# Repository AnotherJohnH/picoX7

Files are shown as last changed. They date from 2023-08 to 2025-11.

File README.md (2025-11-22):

# picoX7

picox7

A software simulation of the Yamaha DX7 with a USB and physical MIDI interface for the Raspberry Pi Pico

Slightly boring [video](https://youtu.be/ZSuNV67vHK8) of the picoX7 playing the Yamaha DX7 ROM cartridge 1A patches...

picoX7 rom1A (https://youtu.be/ZSuNV67vHK8)

## Status

Done...
   + I2S (via PIO) 16-bit stereo DAC interface at 49096 Hz
   + Use of the 2nd Arm Cortex-M, 8 voices per core
   + MIDI in support via UART and USB (including SYSEX in)
   + YM21280 OPS simulation (logarithmic)
   + YM21290 EGS simulation
   + Firmware simulation including pitch envelope, LFO, key sensitivity, level scaling, amplitude modulation
   + DX7 voice patches sounding close

To do...
   - Tune EGS simulation
   - Rate scaling
   - Portamento and glissando
   - Optimise to squeeze in more voices (?)

Limitations...
   - DAC implementation is quite different to the original. Dynamic range might be reduced?
   - Hitachi 6303 (~MC6803) CPU controller and firmware are not being emulated or fully simulated
   - 8 voices are on the left channel and 8 on the right ... stereo output needs to mixed to mono externally

Deviations/enhancements compared to a real DX7...
   + Each voice has it's own LFO
   + Each voice has it's own patch state (in theory when supported could load a different patch into each voice)
   + Support for 128 voice patches (DX7 had 32 internal and 32 cartridge)

See the [software blog](https://github.com/AnotherJohnH/picoX7/wiki/Software-Blog) and [hardware blog](https://github.com/AnotherJohnH/picoX7/wiki/Hardware-Blog)  for more detailed progress updates.

## Hardware

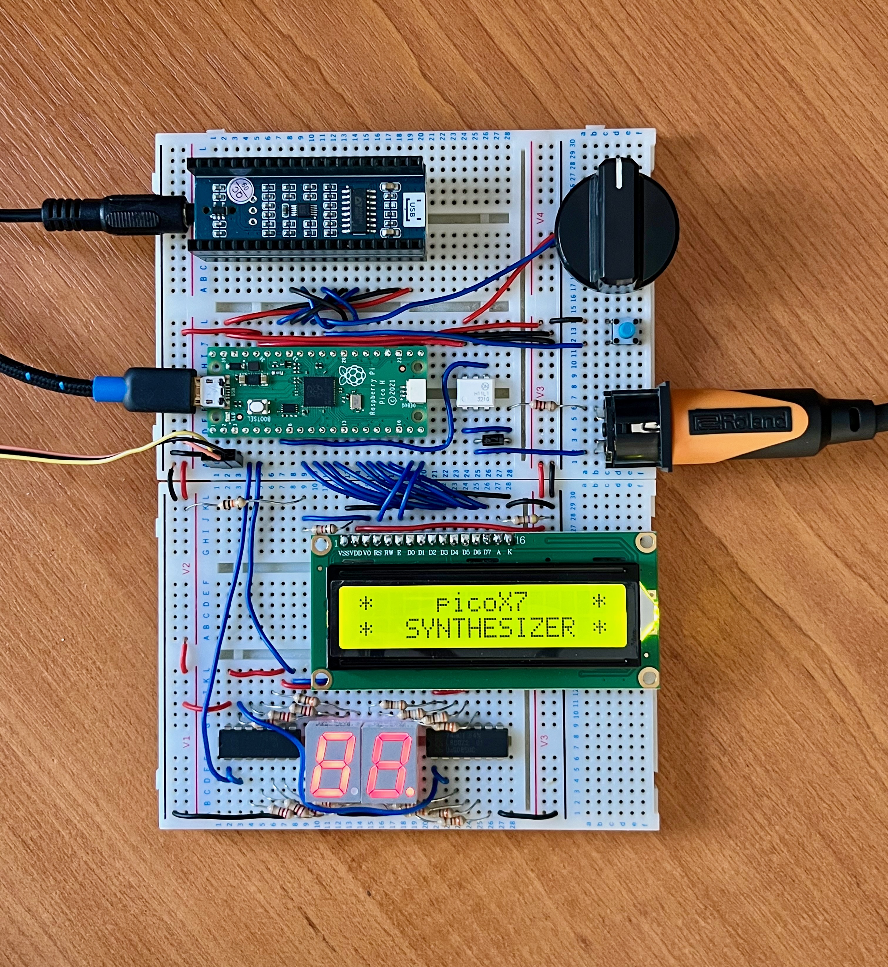
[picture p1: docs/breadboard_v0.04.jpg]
prototype


[Schematic](https://github.com/AnotherJohnH/Hardware/blob/main/picoX7/docs/schematic_v0.05.pdf) for the above.

For more information see [README](https://github.com/AnotherJohnH/Hardware/blob/main/picoX7/README.md) and the [hardware blog](https://github.com/AnotherJohnH/picoX7/wiki/Hardware-Blog)

The Pico is significantly overclocked to 191.08 MHz to support 16 voices and generate a jitter free sample rate of 49096 Hz.

RP2350 Picos as well as the older RP2040 Picos are supported.

## Software

### Checkout

This repo uses git sub-modules, so checkout using --recurse to clone all the
dependent source...

    git clone --recurse https://github.com/AnotherJohnH/picoX7.git

or

    git clone --recurse ssh://git@github.com/AnotherJohnH/picoX7.git

### Software dependencies

+ https://github.com/AnotherJohnH/Platform
+ arm-none-eabi-gcc
+ cmake via UNIX make or auto detection of ninja if installed
+ Python3
+ SDL2 (only for native test target)

### Build

Being developed on MacOS but should build on Linux too.

Indirect build of all supported targets, rpipico, rpipico2 and native with cmake and make (or ninja)...

    make

Build a single hardware target e.g. rpipico2 using cmake...

    mkdir build
    cd build
    cmake -DCMAKE_BUILD_TYPE=Release -DPLT_TARGET=rp2350 -DCMAKE_TOOLCHAIN_FILE=Platform/MTL/rp2350/target/toolchain.cmake ..
    make

flashable images will be found under the build sub-directory here...

    build/<target>/picoX7_RPIPIOC_I2S_DAC.uf2
    build/<target>/picoX7_RPIPIOC_PWM_DAC.uf2
    build/<target>/picoX7_RPIPIOC_PIMORONI_PICO_AUDIO.uf2
    build/<target>/picoX7_RPIPIOC_WAVESHARE_REV2_1.uf2
    build/<target>/picoX7_PIMORONI_VGA_DEMO.uf2

Build the native target...

    mkdir build
    cd build
    cmake -DCMAKE_BUILD_TYPE=Release -DPLT_TARGET=native ..
    make

a runable binary image will be found under the build subdirectory here...

    build/Source/picoX7_NATIVE

## License

This project is licensed under the MIT License - see the [LICENSE](LICENSE) file for details

## Acknowledgements

 + [Ken Shirriff](https://github.com/shirriff) for his very helpful series of [blogs](https://www.righto.com/2021/11/reverse-engineering-yamaha-dx7.html) reverse engineering the YM21280
 + [AJXS](https://github.com/ajxs) for their annotated [disassembly](https://ajxs.me/blog/Yamaha_DX7_Firmware_ROM_Disassembly.html) of the DX7 firmware ROM
 + The [Dexed](https://asb2m10.github.io/dexed) developers for providing an easily accessible DX7 audio reference
 + The raspberry-pi foundation for the innovative [RP2040](https://www.raspberrypi.com/documentation/microcontrollers/rp2040.html)
 + The engineers at [Yamaha](https://www.yamaha.com/en/about/design/synapses/id_009)

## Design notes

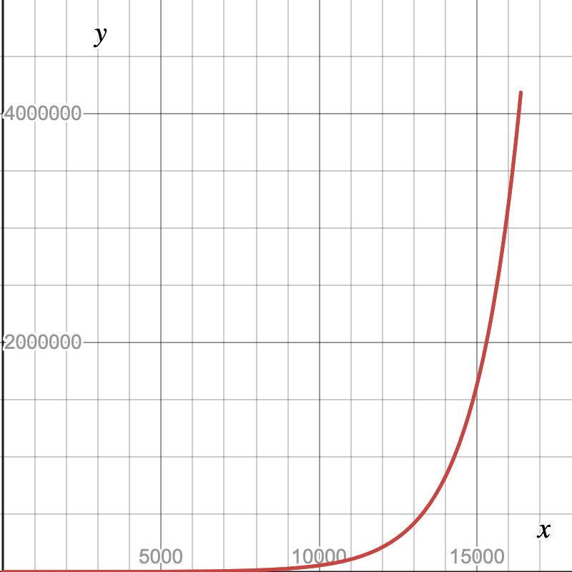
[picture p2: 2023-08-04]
docs/ym21280-exp22.png

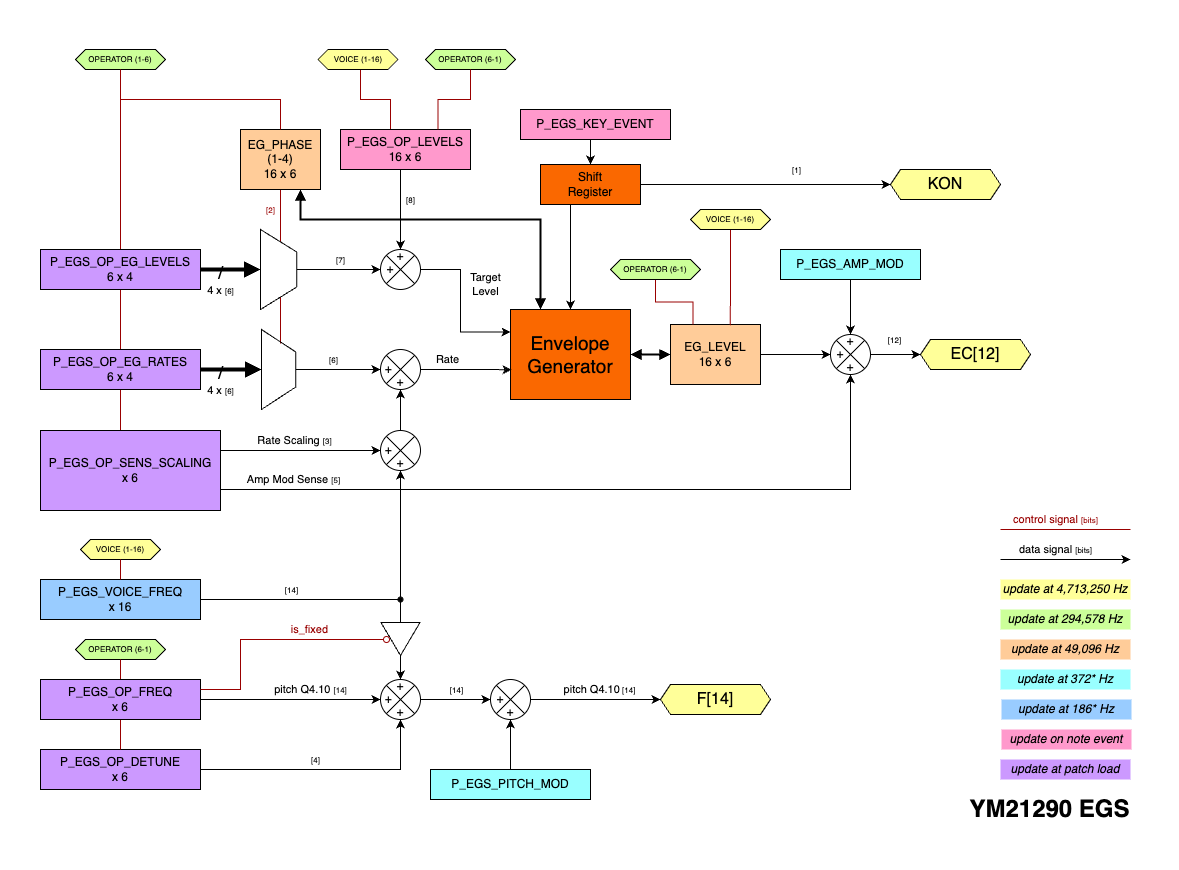
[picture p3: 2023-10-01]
docs/Research/YM21290 EGS.png

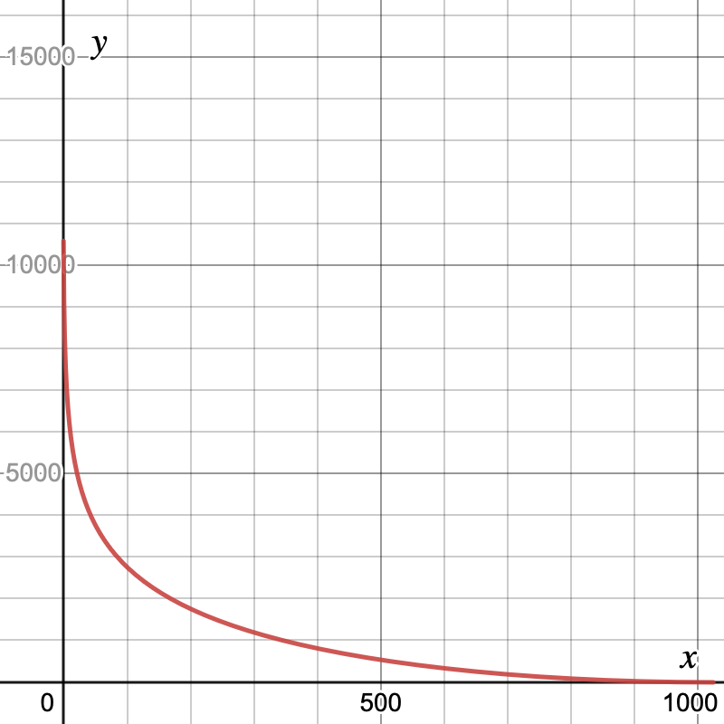
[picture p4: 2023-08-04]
docs/ym21280-log-sine.png

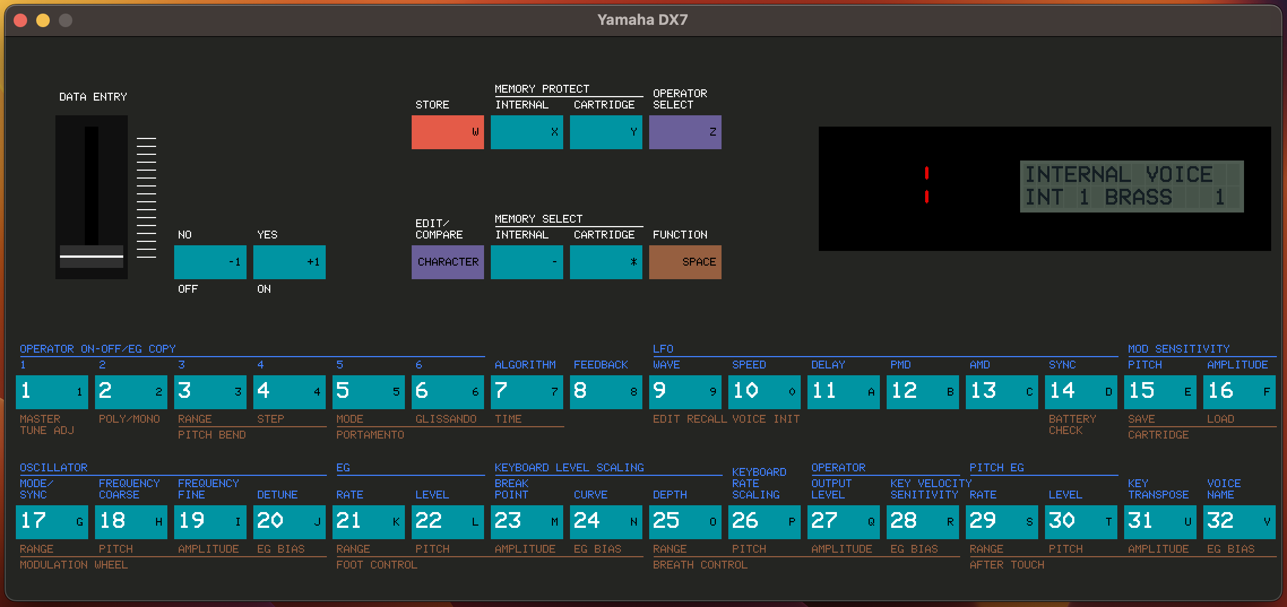
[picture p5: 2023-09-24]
docs/Research/DX7_model.png

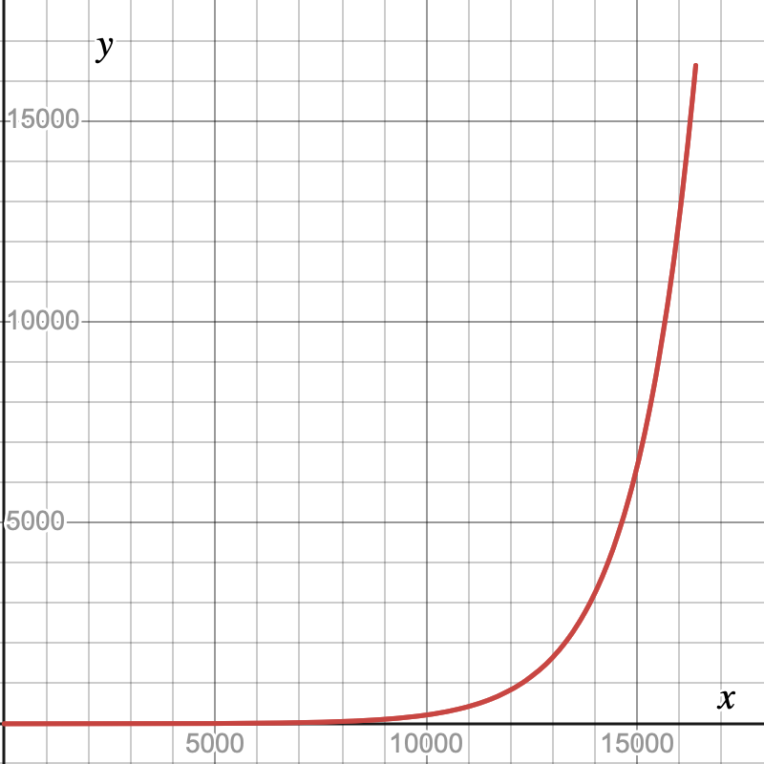
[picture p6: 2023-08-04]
docs/ym21280-exp14.png

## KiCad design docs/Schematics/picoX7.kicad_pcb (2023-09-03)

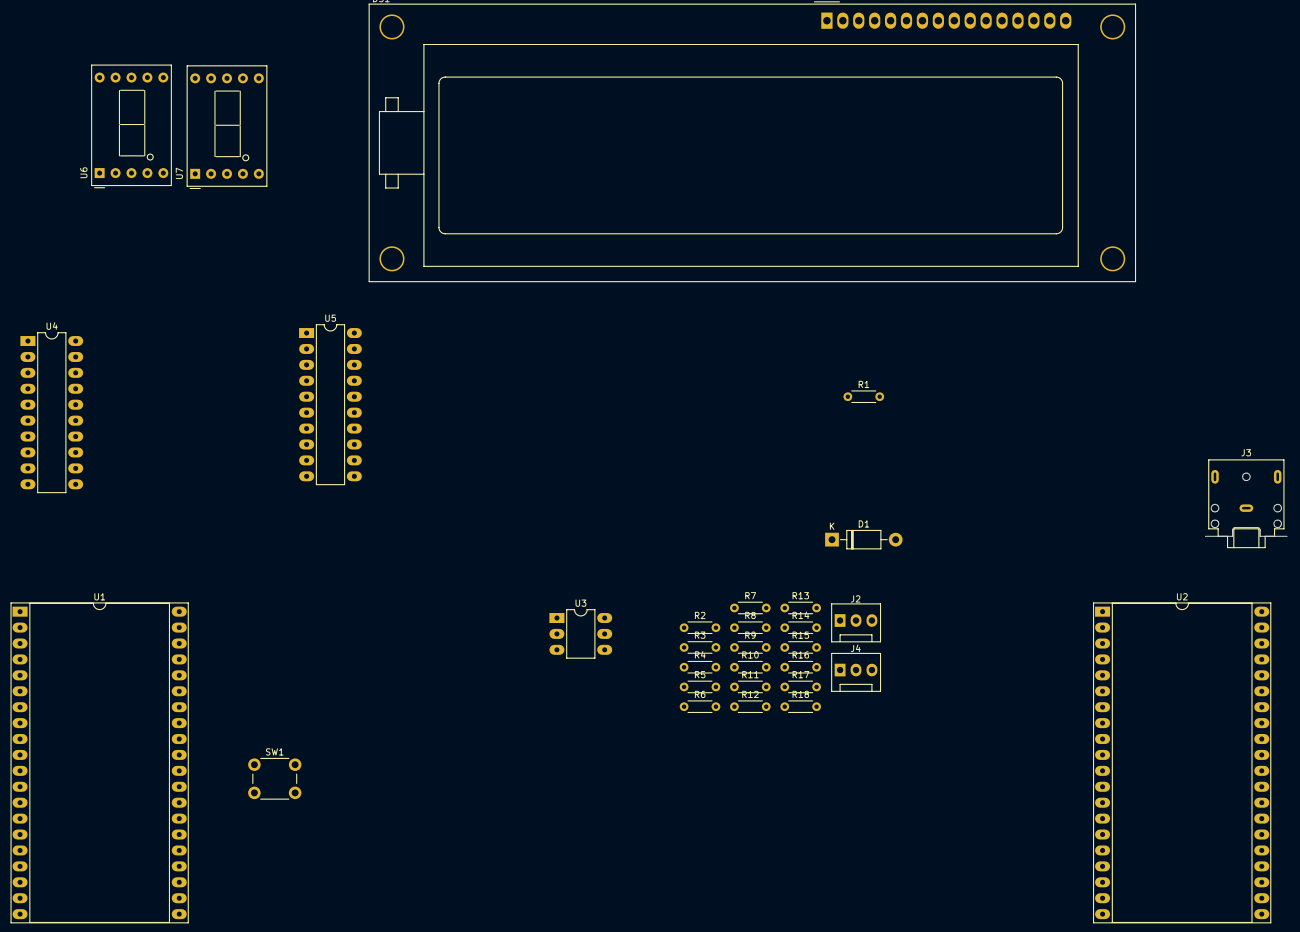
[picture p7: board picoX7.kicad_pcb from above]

Board: 2 copper layers, 31 parts (0 on the bottom side), 43 nets, no tracks yet.

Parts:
D1: 1N4001; D_DO-41_SOD81_P10.16mm_Horizontal
DS1: HY1602E
J2, J4: Debug; FanPinHeader_1x03_P2.54mm_Vertical
J3: Stereo line out; Jack_3.5mm_CUI_SJ1-3523N_Horizontal
R1: 220; R_Axial_DIN0204_L3.6mm_D1.6mm_P5.08mm_Horizontal
R2: 1K; R_Axial_DIN0204_L3.6mm_D1.6mm_P5.08mm_Horizontal
R3, R4, R5, R6, R7, R8, R9, R10, R11, R12, R13, R14, R15, R16, R17, R18: 330; R_Axial_DIN0204_L3.6mm_D1.6mm_P5.08mm_Horizontal
SW1: RST; SW_PUSH_6mm_H5mm
U1: MCU arm Cortex-M0x2; DIP-40_W25.4mm_Socket_LongPads
U2: I2S DAC; DIP-40_W25.4mm_Socket_LongPads
U3: H11L1; DIP-6_W7.62mm_LongPads
U4, U5: 74HCT374; DIP-20_W7.62mm_LongPads
U6, U7: D1X8K-14BL; D1X8K

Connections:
+3V3: U1.36 (3V3), U3.6, U4.20 (VCC), U5.20 (VCC)
+5V: DS1.2 (LEDA), DS1.4 (VDD), R2.2, U1.40 (VBUS)
/1.571072 MHz: U1.34 (GPIO28_ADC2), U2.34 (SCLK)
/12.568576 MHz: U1.31 (GPIO26_ADC0), U2.31 (MCLK)
/49.096 KHz: U1.32 (GPIO27_ADC1), U2.32 (LRCLK)
/31250 baud 8-N-1: U1.7 (GPIO5), U3.4
/D0: DS1.9 (DB0), U1.9 (GPIO6), U4.3 (D0), U5.3 (D0)
/D1: DS1.10 (DB1), U1.10 (GPIO7), U4.4 (D1), U5.4 (D1)
/D2: DS1.11 (DB2), U1.11 (GPIO8), U4.7 (D2), U5.7 (D2)
/D3: DS1.12 (DB3), U1.12 (GPIO9), U4.8 (D3), U5.8 (D3)
/D4: DS1.13 (DB4), U1.14 (GPIO10), U4.13 (D4), U5.13 (D4)
/D5: DS1.14 (DB5), U1.15 (GPIO11), U4.14 (D5), U5.14 (D5)
/D6: DS1.15 (DB6), U1.16 (GPIO12), U4.17 (D6), U5.17 (D6)
/D7: DS1.16 (DB7), U1.17 (GPIO13), U4.18 (D7), U5.18 (D7)
/I2S SD: U1.29 (GPIO22), U2.29 (DIN)
/MIDI in (RX) 115200 baud 8-N-1: J2.2, U1.2 (GPIO1)
/console (TX) 115200 baud 8-N-1: J2.1, U1.1 (GPIO0)
Earth: DS1.1 (LEDK), DS1.3 (VSS), DS1.7 (R/~W), SW1.2, U1.38 (GND), U2.3 (GND), U2.8 (GND), U2.13 (GND), U2.18 (GND), U2.23 (GND), U2.28 (GND), U2.33 (GND), U2.38 (GND), U3.5, U4.1 (OE), U4.10 (GND), U5.1 (OE), U5.10 (GND), U6.3 (CC), U6.8 (CC), U7.3 (CC), U7.8 (CC)
unnamed: D1.2 (A), U3.2
unnamed: D1.1 (K), R1.1, U3.1
unnamed: DS1.8 (E), U1.20 (GPIO15)
unnamed: DS1.6 (RS), U1.19 (GPIO14)
unnamed: J2.3, U1.3 (GND)
unnamed: U1.4 (GPIO2), U5.11 (Cp)
unnamed: U1.5 (GPIO3), U4.11 (Cp)
unnamed: SW1.1, U1.30 (RUN)
unnamed: U1.39 (VSYS), U2.39 (VSYS)
unnamed: R3.1, U6.7 (A)
unnamed: R4.1, U6.6 (B)
unnamed: R5.1, U6.4 (C)
unnamed: R6.1, U6.2 (D)
unnamed: R10.1, U6.5 (DP)
unnamed: R7.1, U6.1 (E)
unnamed: R8.1, U6.9 (F)
unnamed: R9.1, U6.10 (G)
unnamed: R11.1, U7.7 (A)
unnamed: R12.1, U7.6 (B)
unnamed: R13.1, U7.4 (C)
unnamed: R14.1, U7.2 (D)
unnamed: R18.1, U7.5 (DP)
unnamed: R15.1, U7.1 (E)
unnamed: R16.1, U7.9 (F)
unnamed: R17.1, U7.10 (G)

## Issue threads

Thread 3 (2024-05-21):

Using a well-known Pico platform to get users

magwed, 2024-05-21:
Nice project! It would be nice to have a drop-in test possibility to try out your DX7-clone at home with a MIDI-keyboard.

Maybe something like this could be a possible extra target:
https://shop.pimoroni.com/products/pimoroni-pico-vga-demo-base?variant=32369520672851

I have one at home I could test.

Still missing MIDI. Is COM-MIDI still available in the latest build? In windows it used to be resonbly easy via driver to install virtual MIDI-ports by connecting them via COM-ports. Maybe this can be used to hook it up to a DAW/MIDI-player in the nearest PC. Or if possible hooking up a USB-profile for MIDI-input that would be visible in PC. Maybe the other core could handle that?

AnotherJohnH, 2024-06-03:
That's a nice board my only complaint is that it is a bit "output heavy". Would have been nice to have a few more options or headers that could be used for input. A PS/2 keyboard socket would have made me purchase one immediately as a near perfect 80's home computer emulator platform.

However it has a header connected to UART1 that could be used as the physical MIDI in (with a suitable opto-isolater).

I expect driving the I2S on that board would require minimal changes to the existing code. (The PWM audio circuit also intrigues me, must be lower quality than the I2S DAC but would provide an exceptionally cheap alternative for a bread board build of the project.)

I've been temporarily diverted on another project but when I get back to this will see if I can quickly build an image that could receive MIDI on the UART header and drives the I2S pins on this board.

AnotherJohnH, 2024-06-05:
Have speculated support for the Pimoroni VGA Demo base board in the latest release (v0.1.6) [v0.1.6](https://github.com/AnotherJohnH/picoX7/releases/tag/v0.1.6).  To get MIDI into the board you will need to wire up a MIDI serial stream 31.25 kbaud 8-N-1 to the GPIO21 header on the base board. If you can connect and configure correctly to your host computers COM ports then you could test via [PROG_SWEEP.py](https://github.com/AnotherJohnH/picoX7/blob/main/Demo/PROG_SWEEP.py).

Be interested to here if it works.

AnotherJohnH, 2024-06-05:
A build from [aadbbf7](https://github.com/AnotherJohnH/picoX7/commit/aadbbf7b9833c38a64f3811dc1d35406773b0cee) will have some additional debug ...

1. The on-board LED will be lit if any voice is ON - useful to check if MIDI-IN is working
2. Debug console I/O should be routed out via the GPIO20 header on the Pimoroni VGA Demo build - good confidence check

NOTE: Not currently in the uf2s shared for v0.1.6

AnotherJohnH, 2024-06-11:
Currently attempting to add USB device support as a precursor to adding USB host support. If successful this should provide an easy way to control the picoX7 as a MIDI slave from a DAW. (USB host support would allow direct connection to a USB-MIDI controller)

USB is complicated and MIDI-over-USB a whole other complication on top of that, so this may take a while and I might run out of enthusiasm.

However currently have the picoX7 appearing as a low level USB device, which is a good start.

mwedmark, 2024-06-12:
OK Had a Pi Pico H available, so installed that into picoDemo board and wrote 0.16. Also found a FT232H external USB serial circuit that takes 31250 baud as a setting. So next is to mkae sure that the levels are good (3.3V) and try out some small app (yours) and see if there is any sound. It would be really cool to get Midi-yoke going and connect virtual MIDI-port directly from MIDI-out => serial port which I think should be doable. I'll keep you updated.

mwedmark, 2024-06-13:
Thanks for your work! I got sound using the above toolchain in DAC output. I wrote my own program in C# which just sets a program and then a tone! This will be fun to fiddle with going forward. Next task is to connect virtual MIDI-out to this serial port so I can mirror any MIDI-traffic out on the COM porrt and listen to MIDI-files. I'll play the piano myself to maybe I connect it and try it out going forward.

mwedmark, 2024-06-23:
Next level is fixed! It was a little bit of work to get it working in Windows.
First I tried the Hair-less MIDI-Serial driver but that only supports the standard Baud rates.
Then I installed loopMIDI to be able to create virtual MIDI-port and wrote my own .NET program to mirror bytes between MIDI-port and serial port. Works great! So now it is possible to just import a MIDI-piece into a DAW (I use LMMS now) and play notes using the picoX7. Really cool.

AnotherJohnH, 2024-06-24:
Sounds good.

With the latest patches on this project MIDI over USB is working on MacOS. I'm now able to drive the picoX7 directly with MIDI out from a DAW (Abelton live) which is very nice. I would expect MIDI over USB would work on Windows too. With this setup the only hardware required is a USB cable, a pico and a supported I2S device.

mwedmark, 2024-06-24:
Thanks! OK, that will be my next try. I like to play them directly from my MOX-8. I'm going to try and get that build pipe working so I can build my own releases.

Closed 2024-06-18.

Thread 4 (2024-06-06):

USB MIDI in

probonopd, 2024-06-06:
It would be nice to have a USB MIDI in so that we can attach USB MIDI controllers (keyboards) that do not have a DIN-style MIDI connector. For this, the Pico would need to run in USB host mode.

AnotherJohnH, 2024-06-06:
A blocker for this is I use my own SDK "Platform" that does not have USB host support.

Two solutions...

1. Port picoX7 to another raspberry Pi Pico SDK that already has USB host support. All the hardware dependencies are deliberately kept to just [picoX7.cpp](https://github.com/AnotherJohnH/picoX7/blob/main/Source/picoX7.cpp) which should help.
2. Add USB host support to the "Platform" SDK.

TBH I'm not going to do 1. but do have a USB MIDI controller that is nicer than my actual MIDI controller. I'll have a look at the rp2040 dataset to see what's involved in adding support for USB host mode.

AnotherJohnH, 2024-06-07:
... ah yes the world of USB has not simplified itself since I last visited many years ago!

But be e a good challenge and would open up some interesting possibilities for other RPi-Pico based projects.

AnotherJohnH, 2024-06-11:
Currently attempting to add USB device support as a precursor to adding USB host support. If successful this should provide an easy way to control the picoX7 as a MIDI slave from a DAW. But as you state USB host support would allow direct connection to a USB-MIDI controller.

USB is complicated and MIDI-over-USB a whole other complication on top of that, so this may take a while and I might run out of enthusiasm.

However currently have the picoX7 appearing as a low level USB device, which is a good start.

mwedmark, 2024-06-18:
Shortcut, steal with pride:
https://github.com/diyelectromusic/picodexed/tree/main/src

AnotherJohnH, 2024-06-19:
Some small progress, picoX7 now seems to work to some degree as a proper MIDI IN device. [as of patch](https://github.com/AnotherJohnH/picoX7/commit/016d613309dc3bbf84aea4c351807efaf557bc20)
Code is provisional and needs refinement. Timing seems "lumpy"

probonopd, 2024-09-09:
So you attach a MIDI controller (keyboard) using a USB OTG adapter cable to the USB jack on the RPi Pico, and power the RPi Pico via pins GND and VBUS?

AnotherJohnH, 2024-09-09:
Sorry (again) should have been clearer with my "seems to work" comment. MIDI in works but only as a USB device not as a USB host. i.e. MIDI out from my laptop over USB to the picoX7 works.

probonopd, 2024-09-09:
Thanks for the clarification. Do you plan to add USB host mode as well eventually?

AnotherJohnH, 2024-09-09:
Yep, hope to, but my current priority is to add support for the Pico-2 and the Pimoroni pico Audio.

mwedmark, 2024-09-09:
Sound great! I just bought a Pico2 and have the bigger brother picodemo so that combination would be cool to try. I guess that extra processing power will get many more tones poly. Maybe even support with 2 instances would be possible? ;-)

probonopd, 2024-10-02:
Possibly https://github.com/rppicomidi/midi2usbhost/tree/main/C-Code could be helpful? It is C code that does what we need.

probonopd, 2025-01-12:
@AnotherJohnH what do you think, could it work?

AnotherJohnH, 2025-01-19:
Possibly, however I have a personal preference of not including any significant "third party" code in my projects. The RPiPico boot ROM and a few gcc intrinsics being the current exceptions in this project. Feel free to branch and try to integrate that code yourself.

TBH I'm finding physical MIDI in and USB device MIDI in from a DAW satisfy my needs so my desire to spend the time required adding USB host support is still not a priority and would rather spend my time to improve the sound engine simulation.

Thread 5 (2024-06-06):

Display with i2s "backpack"

probonopd, 2024-06-06:
It would be nice if we could use a display module with a i2s "backpack" so that we have to wire up only 4 wires for the display instead of many.

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

AnotherJohnH, 2024-06-06:
Agree that would be nicer.

Have recently added I2C support to the SDK "Platform". Having quickly looked up an I2C 16x2 LCD can see that, unsurprsingly, the internal register set looks the same as the parallel LCD devices. So the work would be...

1.  Write a new version of [MTL/Lcd.h](https://github.com/AnotherJohnH/Platform/blob/a5334979c00c0b1448b7ad0d50a105444d258198/MTL/Lcd.h) ripping out the raw GPIO use and putting in an instance of MTL::I2C [MTL/rp2040/I2C.h](https://github.com/AnotherJohnH/Platform/blob/a5334979c00c0b1448b7ad0d50a105444d258198/MTL/chip/rp2040/I2C.h)
2. Add another hardware target to the build with some conditional compilation in [picoX7.cpp](https://github.com/AnotherJohnH/picoX7/blob/main/Source/picoX7.cpp) to select the I2C LCD driver.

Might buy one to play with when I next order some bits.

AnotherJohnH, 2024-06-07:
Have completed the trivial parts here [721a3eb](https://github.com/AnotherJohnH/picoX7/commit/721a3eb9524ba64c57f75a8670e3a4f91ae0ac6d)
Remaining work is to complete implementation of [Platform/MTL/AlphaNumLcd_I2C.h](https://github.com/AnotherJohnH/Platform/blob/master/MTL/AlphaNumLcd_I2C.h)

AnotherJohnH, 2024-09-08:
Support completed. Works for me with an AiP31068L based I2C 16x2 LCD from Waveshare via the I2C1 on pins 19 and 20. Thankyou for the suggestion that's a nice improvement. See the latest release [v0.18](https://github.com/AnotherJohnH/picoX7/releases/tag/v0.18)

AnotherJohnH, 2024-09-08:
Support completed. Works for me with an AiP31068L based I2C 16x2 LCD from Waveshare via the I2C1 on pins 19 and 20. Thankyou for the suggestion that's a nice improvement. See the latest release [v0.18](https://github.com/AnotherJohnH/picoX7/releases/tag/v0.18)

probonopd, 2024-09-28:
Which address does your display use?

AnotherJohnH, 2024-09-29:
See Platform/MTL/AlphaNumLcd_I2C.h. The address is passed as the only argument to the display driver constructor. But has a default value that matches the display I use which is 0x3E. This values is masked with 0x7F and written unshifted into the RP I2C peripherals IC_TAR (target address) register. So if you need a different address add { <addr } to the instantiation of the LCD driver in picoX7.cpp e.g.

```
static MTL::AlphaNumLcd<MTL::I2C1_P19_P20,
                        /* COLS */ 16,
                        /* ROWS */ 2> lcd { 0xHH };
```

I notice in the official SDK that similar devices use an address of 0x27 so that might be worth trying.  Maybe the device I have, a "Waveshare LCD 1602 I2C" is unusual. To be honest I struggled to find this rather important information for the display I have, on either the PiHut or Waveshare web pages. Until eventually I saw this line in a micro python example they published ...

```
#Device I2C Arress
LCD_ADDRESS  = (0x7C>>1)
```

Which, obviously, is a rather cryptic way of writing 0x3E.

AnotherJohnH, 2024-09-29:
... will post a patch making the I2C address clearer in picoX7.cpp

AnotherJohnH, 2024-09-29:
... see https://github.com/AnotherJohnH/picoX7/commit/d2f77267cb0e3e65a20598f3285e89cd395b69f4

probonopd, 2024-09-30:
Thanks @AnotherJohnH. Indeed all the generic displays I have use 0x27, so I will try that.

probonopd, 2024-09-30:
All that really happens now is that the backlight on the display (the one from the original post) gets switched off, around the time when `# 001 NAME BRASS   1  ALG 22 FBK 7 SYNC on  PMS 3 TRN 0` appears on the serial console:

```
Program  : picoX7 (WaveShare Rev2.1 I2C LCD)
Author   : Copyright (c) 2023 John D. Haughton
Version  : 0.18
Commit   : 2a2902ada41b07839b052e695fa4de73233b510b
Built    : 07:49:14 Sep 30 2024
Compiler : 9.2.1 20191025 (release) [ARM/arm-9-branch revision 277599]

# 001 NAME BRASS   1  ALG 22 FBK 7 SYNC on  PMS 3 TRN 0
LFO WAV sin SPD 37 DLY 00 PMD 05 AMD 00 SYNC off
OP AMS FREQ    DET R1 R2 R3 R4  L1 L2 L3 L4  BPT   CURVE    DEPTH RTE OUT KVS
6   0  R  1.00  0  49 99 28 68  98 98 91 00  39  -exp -exp  54 50  4   82  2
5   0  R  1.00  1  77 36 41 71  99 98 98 00  39  +lin +lin  00 00  0   98  2
4   0  R  1.00  0  77 36 41 71  99 98 98 00  39  +lin +lin  00 00  0   99  2
3   0  R  1.00 -2  77 76 82 71  99 98 98 00  39  +lin +lin  00 00  0   99  2
2   0  R  0.50  7  62 51 29 71  82 95 96 00  27  +lin -exp  00 07  0   86  0
1   0  R  0.50  7  72 76 99 71  99 88 96 00  39  +lin +lin  00 14  0   98  0
PITCH EG           84 95 95 60  50 50 50 50
```

AnotherJohnH, 2024-09-30:
Ugg :-( I guess that means the I2C address is working but the I2C interface in the Waveshare device I have is not the same as the "generic displays" that usually live at 0x27. Will dig into this a bit further when I get a chance. Do you know the part number of the I2C device on your display?

probonopd, 2024-10-01:
I think they are all using various [8574](https://www.ti.com/lit/ds/symlink/pcf8574.pdf) compatible chips. Mine says "8574T".

AnotherJohnH, 2024-10-01:
So seems there are (at least) two types of I2C 16x2 LCD....

1. The one you have uses a generic I2C bridge chip (the PCF8574) to drive the parallel interface to the old style HD44780 LCD display driver. I guess back-pack was the clue I missed. [I2C 16x2 Arduino LCD display module](https://thepihut.com/products/i2c-16x2-arduino-lcd-display-module)
2. The device I have, which uses an all in one I2C LCD driver chip.  [LCD 1602 I2C module](https://thepihut.com/products/lcd1602-i2c-module)

probonopd, 2024-10-02:
Could it be that you forgot to push Platform d6af84a04098e0b8219930b8238eb8fdf3f17c61? I am currently getting

```
Fetching submodules
  /usr/bin/git submodule sync
  /usr/bin/git -c protocol.version=2 submodule update --init --force
  Submodule 'Platform' (https://github.com/AnotherJohnH/Platform.git) registered for path 'Platform'
  Cloning into '/home/runner/work/picoX7/picoX7/Platform'...
  Error: fatal: remote error: upload-pack: not our ref d6af84a04098e0b8219930b8238eb8fdf3f17c61
  Error: fatal: Fetched in submodule path 'Platform', but it did not contain d6af84a04098e0b8219930b8238eb8fdf3f17c61. Direct fetching of that commit failed.
  Error: The process '/usr/bin/git' failed with exit code 128
```

This kind of error could be caught easily if continuous integration would be merged:

* https://github.com/AnotherJohnH/picoX7/pull/9

AnotherJohnH, 2024-10-02:
Oh, sorry about that have pushed the missing Platform patch.

probonopd, 2024-10-02:
Moving in the right direction, but not quite yet there.

When I power cycle the display, I immediately see a blinking square over a _ character. Then the screen shows the string "NTERND" followed by blanks, and the blinking square over a _ character is in the 4th from the right on the second line.

I would not be entirely surprised if some "waits" were missing, or something small along those lines.

AnotherJohnH, 2024-10-04:
After a reset the display should be....
```
*    picoX7    *
*  SYNTHESIZER *
```
and then after 2.5 seconds...
```
INTERNAL VOICE
INT 1 BRASS   1
```
so yep, seems close. I'll double check the code and the timings in particular.

AnotherJohnH, 2024-10-04:
Guessing it's got through the initialisation ok-ish.  So the general byte send code is possibly the broken part.

I'd copied the delays that I'd used in the parallel version of the driver which are (setup) 10us and (hold) 38us. The Python you linked had no delays in this area, but then Python is going to be so slow that it probably covers the requirement without trying. Looking at the C in the official pico-example can see some massive 600us delays and also the code takes time to setup the data nibble before asserting the E pin, again with a 600us delay.

The data sheet does not support the need to setup the data before asserting E, it is clear that the data is captured on the falling edge of E, which makes me suspicious of the 600us too. TBH to follow the data sheet all these drivers (mine included) should be sampling the busy flag pin instead of delays. Which I guess us coders are too lazy to do!

Have posted a [patch](https://github.com/AnotherJohnH/picoX7/commit/39e6b5d68a0a7fa364d3d5b94330636c6465c3b7) which updates the timings to 600us. If I was able to test would have tuned this down until it was just working and then doubled it.

probonopd, 2024-10-06:
Sorry to be a pain, but now I get strange special characters on the screen. I do see that the display content changes after 2.5 seconds (so it's alive), but unfortunately nothing is readable. The characters being shown seem to be entirely reproducible across reboots.

If you can give me instructions on what to change/test, I can do it.

Closed 2024-09-08.

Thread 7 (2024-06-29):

DX7 SYSEX download over USB MIDI broken

AnotherJohnH, 2024-06-29:
Be nice to be able to download SYSEX patches over USB MIDI say from Dexed. This is not working at the moment and the assumption is that these long SYSEX messages are sent using the "High Bandwidth" Data Transfer Mechanism.
Currently have only implemented the basic MIDI stream.

AnotherJohnH, 2024-06-29:
LOL seems from the USB MIDI spec. that "bulk transfer" is  the basic MIDI messages, and "Transfer bulk" is what this enhancement is about!

AnotherJohnH, 2024-06-30:
Turns out it was partly my misuse of Dexed. To send SYSEX to the picoX7 you need to also select the picoX7 as the DX7 out in the PARM popup window. With this change a SYSEX starts to be received by the picoX7 using the normal "bulk transfer" so a "Transfer bulk" end-point is not needed.

However the picoX7 crashes cacaphonically halfway through the SYSEX download.

AnotherJohnH, 2024-06-30:
Cacaphonic crash was down to too much debug printf in the USB IRQ handler. So have downloaded a dexed patch. But still testing...

AnotherJohnH, 2025-01-19:
There was also a silly bug in the generic MIDI SySex handling code in Platform. Seems fixed now as of [https://github.com/AnotherJohnH/picoX7/commit/cc8704fef1c9a08d68a0d6125e64171c9ef9e741](patch)

Closed 2025-01-19.

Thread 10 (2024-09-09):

How to use the native target on Linux?

probonopd, 2024-09-09:
How to get MIDI input into the native target on Linux and/or sound out of it?

```
./picoX7_NATIVE

Program  : picoX7 (native)
Author   : Copyright (c) 2023 John D. Haughton
Version  : 0.18
Commit   : 6381560b020c1a3617568663ccafd5c57f9183a7
Built    : 18:41:18 Sep  9 2024
Compiler : 9.4.0

# 001 NAME BRASS   1  ALG 22 FBK 7 SYNC on  PMS 3 TRN 0
LFO WAV sin SPD 37 DLY 00 PMD 05 AMD 00 SYNC off
OP AMS FREQ    DET R1 R2 R3 R4  L1 L2 L3 L4  BPT   CURVE    DEPTH RTE OUT KVS
6   0  R  1.00  0  49 99 28 68  98 98 91 00  39  -exp -exp  54 50  4   82  2
5   0  R  1.00  1  77 36 41 71  99 98 98 00  39  +lin +lin  00 00  0   98  2
4   0  R  1.00  0  77 36 41 71  99 98 98 00  39  +lin +lin  00 00  0   99  2
3   0  R  1.00 -2  77 76 82 71  99 98 98 00  39  +lin +lin  00 00  0   99  2
2   0  R  0.50  7  62 51 29 71  82 95 96 00  27  +lin -exp  00 07  0   86  0
1   0  R  0.50  7  72 76 99 71  99 88 96 00  39  +lin +lin  00 14  0   98  0
PITCH EG           84 95 95 60  50 50 50 50
```

When I play notes on an attached MIDI controller (keyboard), I hear no sound and the output on the screen does not change.
When I do `sudo cat /dev/midi3` and press some keys on the keyboard, I do see activity there.

How to analyze/debug this?

AnotherJohnH, 2024-09-09:
Ouch, sorry, I should use Linux more often! If you look in `Platform/PLT/Linux/CMakeLists.txt` you will find that the MIDI modules are stubs. e.g. compare with the `macOS` sub-directory which has actual implementations.

I have a Linux VM. Be happy to have a quick look.

AnotherJohnH, 2024-09-09:
This [patch](https://github.com/AnotherJohnH/picoX7/commit/58a0eb7a6a6f1b0d9cf4a139e7179419651d6804) should help get something working. There seems to be some significant latency. Maybe it's because I used a Linux VM or maybe it's my misuse of the Linux API?

Closed 2024-09-15.

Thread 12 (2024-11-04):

Electrical note to connect UART MIDI keyboard

sysop8866, 2024-11-04:
Hello!
I suggest you insert a 470ohm pullup resistor between pin(7)-GPIO5 Rx MIDI and 3.3V.
Without this resistor I cannot decode any data from the MIDI keyboard.
Now with this modification it works perfectly.
I compiled your software for both the RP2040 and RP2350 boards with an external DAC PCM5102 and it works well.
I congratulate you for the excellent work you have done.
Thanks
Daniele
P.S.
Sorry for my bad English!

AnotherJohnH, 2025-01-12:
(sorry for the delay in response had other priorities)
Thank you for the feedback, particularly the missing pull up, good spot!
Have posted a software fix here https://github.com/AnotherJohnH/picoX7/commit/e0d8dabb997fa5f0a68e6075255a5b83199fc15f that restores the internal pull up in software. Must have got lost at some point.

AnotherJohnH, 2025-01-12:
Should be fixed now

Closed 2025-01-12.

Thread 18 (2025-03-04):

Final output level

AnotherJohnH, 2025-03-04:
The final output level for different algorithms seems too variable. The more carriers in the final mix the lower the level. This is obviously due to the compensation factor but maybe is resolved in the real thing by the SF[3:0] signal from the OPS to the funky DAC circuit.

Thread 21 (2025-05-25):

I2C (LCD display) and UART  RX (physical MIDI) broken on RP2350

AnotherJohnH, 2025-05-25:
oops not properly tested

AnotherJohnH, 2025-05-25:
Fixed by [patch](https://github.com/AnotherJohnH/picoX7/commit/ccd13932d50590748810dbff510bee8081c6cbcd)

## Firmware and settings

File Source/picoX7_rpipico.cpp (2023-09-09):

//------------------------------------------------------------------------------
// Copyright (c) 2023 John D. Haughton
//
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
// \brief DX7 simulation for Raspberry Pi Pico

#include <cstdio>
#include <unistd.h>

#include "STB/MIDIInterface.h"

#include "MTL/MTL.h"
#include "MTL/Digital.h"
#include "MTL/Pins.h"
#include "MTL/PioAudio.h"
#include "MTL/Led7Seg.h"
#include "MTL/Lcd.h"
#include "MTL/rp2040/Uart.h"
#include "MTL/rp2040/Clocks.h"
#include "MTL/rp2040/Adc.h"

#include "Usage.h"
#include "DX7/Synth.h"

static const unsigned SAMPLE_RATE = 49096;                   // DAC sample rate (Hz)
static const unsigned TICK_RATE   = 375;                     // 6800 firmware tick (375 Hz)
static const unsigned BUFFER_SIZE = SAMPLE_RATE / TICK_RATE; // DAC buffer size (samples)
static const unsigned NUM_VOICES  = 6;                       // Polyphony

//! Select a system clock with clean division to 49.1 KHz
//namespace MTL { Clocks::SysFreq clocks_sys_freq = Clocks::SYS_FREQ_137_48_MHZ; }

//! Select a system clock with clean division to 49.095 KHz
//namespace MTL { Clocks::SysFreq clocks_sys_freq = Clocks::SYS_FREQ_157_10_MHZ; }

//! Select a system clock with clean division to 49.096 KHz
namespace MTL { Clocks::SysFreq clocks_sys_freq = Clocks::SYS_FREQ_191_08_MHZ; }


// --- RP2040 module LED --------------------------------------------------------------

MTL::Digital::Out<MTL::PIN_LED1> led;


// --- MIDI-in -----------------------------------------------------------------

//! MIDI in at 31250 baud
class MidiIn1 : public MIDI::Interface
{
public:
   MidiIn1(MIDI::Instrument& instrument)
      : MIDI::Interface(instrument)
   {}

   bool empty() const override { return uart.empty(); }

   uint8_t rx() override { return uart.rx(); }

private:
   MTL::Uart1 uart{31250, 8, MTL::UART::NONE, 1};
};


// --- debug MIDI-in -----------------------------------------------------------

//! Slow MIDI in via the console UART
class MidiIn0 : public MIDI::Interface
{
public:
   MidiIn0(MIDI::Instrument& instrument)
      : MIDI::Interface(instrument)
   {}

   bool empty() const override { return MTL_getch_empty(); }

   uint8_t rx() override { return MTL_getch(); }
};


// --- 7-segment LED display ---------------------------------------------------

static MTL::Led7Seg</* PIN_CLK */  MTL::PIN_5,
                    /* PIN_DATA */ MTL::PIN_4,
                    /* NUM_DIGITS */ 2> led_7seg;

void SynthIO::displayLED(unsigned number)
{
   led_7seg.printDec(number, number >= 100 ? 0 : 3);
}


// --- 16x12 LCD display -------------------------------------------------------

static MTL::Lcd</* PIN_DATA */   MTL::PIN_9,
                /* PIN_R_S */    MTL::PIN_19,
                /* PIN_ENABLE */ MTL::PIN_20,
                /* COLS */       16,
                /* ROWS */       2,
                /* DL_8BIT */    true> lcd;

void SynthIO::displayLCD(unsigned row, const char* text)
{
   lcd.move(0, row);
   lcd.print(text);
}


// --- ADC ---------------------------------------------------------------------

MTL::Adc adc;

unsigned SynthIO::readSliderADC()
{
   static bool first_pass{true};

   if (first_pass)
   {
      adc.startCont(/* channel */ 0);
   }

   return adc.scaledResult(100);
}


// -----------------------------------------------------------------------------

static Usage                            usage {};
static Synth<NUM_VOICES, /* AMP_N */ 8> synth {};

// --- DAC ---------------------------------------------------------------------

//! 49.1 KHz I2S DAC, with pinout for Waveshare Pico-Audio
//  buffer sized to give a 375 Hz tick
static MTL::PioAudio<MTL::Pio0,BUFFER_SIZE> audio {SAMPLE_RATE,
                                                   MTL::PIN_27,  // MCLK
                                                   MTL::PIN_29,  // SD
                                                   MTL::PIN_32}; // LRCLK + SCLK
PIO_AUDIO_ATTACH_IRQ_0(audio);

//! DAC pump call-back
void MTL::PioAudio_getSamples(uint32_t* buffer, unsigned n)
{
   usage.start();

   synth.tick();

   for(unsigned i = 0; i < n; ++i)
   {
      int16_t sample = synth();

      // Same 16-nit sample to left and right audio streams
      buffer[i] = (sample << 16) | (sample & 0xFFFF);
   }

   usage.end();
}


// --- Entry point -------------------------------------------------------------

int MTL_main()
{
   // Starting
   led = true;

   // Clear screen and cursor to home
   printf("\e[2J");
   printf("\e[1,1H");

   printf("\n");
   printf("Program  : picoX7\n");
   printf("Author   : Copyright (c) 2023 John D. Haughton\n");
   printf("Version  : %s\n", MTL_VERSION);
   printf("Commit   : %s\n", MTL_COMMIT);
   printf("Built    : %s %s\n", __TIME__, __DATE__);
   printf("Compiler : %s\n", __VERSION__);
   printf("\n");

   MidiIn0 midi_in0 {synth};
   MidiIn1 midi_in1 {synth};

   synth.programChange(0, 0);

   audio.start();

   while(true)
   {
      midi_in0.tick();
      midi_in1.tick();

#if 0
      puts("\033[H");
      printf("FLASH: %2u%%   ", usage.getFLASHUsage());
      printf("RAM: %2u%%   ", usage.getRAMUsage());
      printf("CPU: %2u%%\n", usage.getCPUUsage());

      usleep(500000);
#endif
   }

   return 0;
}

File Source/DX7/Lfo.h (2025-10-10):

//-------------------------------------------------------------------------------
// Copyright (c) 2023 John D. Haughton
// SPDX-License-Identifier: MIT
//-------------------------------------------------------------------------------

// \brief DX7 firmware simulation - LFO
//
// Credit to AJXS for his excellent disassembly of the DX7 firmware ROM

#pragma once

#include "SysEx.h"

//! DX7 LFO simulation
class Lfo
{
public:
   Lfo() = default;

   //! Get amplitude modulatiion factor (0..FF)
   uint8_t getAmpMod() const { return amp_mod; }

   //! Get pitch modulatiion factor (0..FF)
   uint8_t getPitchMod() const { return pitch_mod; }

   //! Get current amplitude output value (2's comp 8-bit)
   int8_t getAmpOutput() const { return output; }

   //! Get current pitch output value (2's comp 8-bit)
   int8_t getPitchOutput() const { return (output * pitch_mod_sense) >> 8; }

   //! Configure from SysEx program
   void load(const SysEx::Voice& patch)
   {
      // Compute LFO phase increment from LFO speed
      // Scale 0..99 to full scale 8-bit e.g. 0..255
      uint8_t  speed = (patch.lfo.speed * 660) >> 8;
      unsigned scale = 11;

      if (speed == 0)
      {
         speed = 1;                     // LFO speed 0 => 11
      }
      else if (speed >= 160)
      {
         scale += (speed - 160) >> 2;   //      LFO speed 63..99 => 1782..8670
      }                                 // else LFO speed  1..62 =>   11..1749

      phase_inc = scale * speed;


      // Compute LFO delay increment from LFO delay
      // Invert 0..99 => 99..0
      // and treat as an 7-bit floating point value _EEEMMMM
      uint8_t  delay   = 99 - patch.lfo.delay;
      uint8_t  exp     = 7 - (delay >> 4);
      uint16_t mantisa = (0b10000 | (delay & 0b1111)) << 9;
      delay_inc        = mantisa >> exp;


      // Scale 0..99 to full scale 8-bit e.g. 0..255
      pitch_mod_depth = (patch.lfo.pitch_mod_depth * 660) >> 8;

      // Scale 0..99 to full scale 8-bit e.g. 0..255
      amp_mod_depth = (patch.lfo.amp_mod_depth * 660) >> 8;

      waveform = patch.lfo.waveform;

      // Scale 0..7 to full scale 8-bit e.g. 0..255
      const uint8_t pitch_mod_sense_table[8] = {0, 10, 20, 33, 55, 92, 153, 255};
      pitch_mod_sense = pitch_mod_sense_table[patch.pitch_mod_sense];

      sync = patch.lfo.sync;
   }

   //! Start of note
   void keyOn()
   {
      delay_accum = 0;
      fade_in     = 0;

      if (sync)
      {
         phase_accum = MAX_PHASE;
      }
   }

   //! Step the LFO and return current output (should be called at 375 Hz)
   void tick()
   {
      // Evaluate delay and fade-in
      unsigned next_delay_value = delay_accum + delay_inc;
      if (next_delay_value < 0xFFFF)
      {
         // Still delayed
         delay_accum = next_delay_value;
      }
      else
      {
         // Delay complete
         delay_accum = 0xFFFF;

         // Compute fade-in => Use MSB of delay increment for fade-in increment
         unsigned fade_in_inc  = delay_inc > 0xFF ? delay_inc >> 8 : 1;
         unsigned next_fade_in = fade_in + fade_in_inc;
         fade_in               = next_fade_in < 0xFF ? next_fade_in : 0xFF;
      }

      // Increment LFO phase
      phase_accum += phase_inc;

      switch(waveform)
      {
      case SysEx::TRIANGLE:
         {
            output = phase_accum >> 7;
            if (phase_accum < 0)
            {
               output = ~output;
            }
            output += 0x80;
         }
         break;

      case SysEx::SAW_DOWN:
         output = ~(phase_accum >> 8);
         break;

      case SysEx::SAW_UP:
         output = phase_accum >> 8;
         break;

      case SysEx::SQUARE:
         output = phase_accum < 0 ? 127 : -128;
         break;

      case SysEx::SINE:
         {
            static const uint8_t sine_table[64] =
            {
               0x02, 0x05, 0x08, 0x0B, 0x0E, 0x11, 0x14, 0x17,
               0x1A, 0x1D, 0x20, 0x23, 0x26, 0x29, 0x2C, 0x2F,
               0x32, 0x35, 0x38, 0x3A, 0x3D, 0x40, 0x43, 0x45,
               0x48, 0x4A, 0x4D, 0x4F, 0x52, 0x54, 0x56, 0x59,
               0x5B, 0x5D, 0x5F, 0x61, 0x63, 0x65, 0x67, 0x69,
               0x6A, 0x6C, 0x6E, 0x6F, 0x71, 0x72, 0x73, 0x75,
               0x76, 0x77, 0x78, 0x79, 0x7A, 0x7B, 0x7C, 0x7C,
               0x7D, 0x7D, 0x7E, 0x7E, 0x7F, 0x7F, 0x7F, 0x7F
            };

            unsigned index = (phase_accum >> 8) & 0x3F;
            if ((phase_accum & 0x4000) != 0)
            {
               index ^= 0x3F;
            }
            output = sine_table[index];
            if (phase_accum < 0)
            {
               output = ~output;
            }
         }
         break;

      case SysEx::SAMPLE_AND_HOLD:
         if ((phase_accum - MIN_PHASE) < phase_inc)
         {
            sample_hold_accum = sample_hold_accum * 179 + 11;
         }
         output = sample_hold_accum;
         break;
      }

      amp_mod   = (fade_in * amp_mod_depth) >> 8;
      pitch_mod = (fade_in * pitch_mod_depth) >> 8;
   }

private:
   using Phase = int16_t;

   static const Phase MAX_PHASE = 0x7FFF;
   static const Phase MIN_PHASE = -0x8000;

   // Configuration from patch
   uint16_t        phase_inc{0};              //!< DX7 var @ 0x2320
   uint16_t        delay_inc{0};              //!< DX7 var @ 0x2322
   SysEx::LfoWave  waveform{SysEx::TRIANGLE}; //!< DX7 var @ 0x2324
   uint8_t         amp_mod_depth{0};          //!< DX7 var @ 0x2326
   uint8_t         pitch_mod_depth{0};        //!< DX7 var @ 0x2325
   uint8_t         pitch_mod_sense{0};        //!< DX7 var @ 0x2327
   bool            sync {false};

   // State
   Phase    phase_accum{MAX_PHASE};   //!< DX7 var @ 0xD7:D8
   uint8_t  sample_hold_accum{0};     //!< DX7 var @ 0xDA
   uint8_t  fade_in{0};               //!< DX7 var @ 0xDB
   uint16_t delay_accum{0};           //!< DX7 var @ 0xDD:DE

   // Outputs
   int8_t   output{0};                //!< DX7 var @ 0xD9
   uint8_t  amp_mod{};
   uint8_t  pitch_mod{};
};

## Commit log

2023-06-12 Update to PIO I2S driver to fix SD alignment
2023-06-18 Working polyphonic synth with Simple voice - mbedLPC1768 and native targets broken XXX
    [picosynth_rpipico.cpp]
2023-06-18 Rework to allow mbedLPC1768 and nativew builds
    [picosynth_mbedLPC1768.cpp, picosynth_rpipico.cpp]
2023-07-02 Some fixes (but still extremely broken!)
    [picoX7_rpipico.cpp]
2023-07-03 Some DX7 fidelity fixes - still a long way off
    [picoX7_rpipico.cpp]
2023-07-06 Prepare for pitch EG
2023-07-07 Pitch bend does
2023-07-13 Switch voice programming to unpacked SysEx structure
2023-07-13 Add bread board snap
2023-07-17 Update UART implementation for more reliable debug and MIDI comms
2023-07-17 Overclocked to 191MHz to achieve 8 voices at 49096Hz - now seems more reliable now the UARTs are buffered
2023-07-28 Tidy up Python a test driver
2023-07-30 Cut back to 6 voice at 191 MHz for now - seems to solve audio glitches and occasional crash
    [picoX7_rpipico.cpp]
2023-08-05 Preparing to switch OPS to a logarithmic implementation
2023-08-28 Add schematic files (KiCad)
    [picoX7.kicad_pcb, picoX7.kicad_sch]
2023-08-30 Update schematic with planned extensions
    [picoX7.kicad_sch]
2023-09-03 Add 7-segment display of current program number
2023-09-03 Update schematic to reflect changes to LED display
    [picoX7.kicad_pcb, picoX7.kicad_sch]
2023-09-05 Minor schematic update
    [picoX7.kicad_sch]
2023-09-07 Update Platform for improved timer support
2023-09-09 Refactor docs directories
    [picoX7.kicad_pcb, picoX7.kicad_sch]
2023-09-09 Add ADC slider input
    [picoX7.kicad_sch]
2023-09-09 Deploy module LED as start up diagnostic
2024-06-05 Add build support for PiMoroni VGA demo board
2024-06-05 Add "any voice on debug" via on-board LED
2024-06-05 Route console debug via the MIDI uart for Pimoroni VGA board
2024-06-07 Add support for I2C LCD Note: Implementation in Platform is not working yet
2024-06-17 Now appears as a USB device - non-functional
2024-06-17 Some USB device updates - still non-functional
2024-06-19 USB MIDI in (device mode) starting to work
2024-06-21 Tidy away some debug printf
2024-06-22 Some tidy and refactor of the USB device implementation
2024-07-06 Tidy HW configuration - debug MIDI via console removed no longer required now USB MIDI works - not using the ADC at the moment so Waveshare DAC only builds in piggy-back mode
2024-07-06 Common source code for Pico and native builds
2024-07-06 Move profiling reporting to LCD and 7-seg LED
2024-07-07 Move synth tick into the main thread out of the audio IRQ handler + seems to avoid some audio glitches
2024-07-08 Get samples 2 at a time for a small performance gain
2024-07-19 Update Platform as an attempt to fix the cacaphonic crash
    - May have been DMA channel overrun
2024-09-08 Update Platform to support I2C 16x2 LCD
2024-09-08 Build support for Raspberry Pi Pico2 builds but not working yet
2024-09-15 Pimoroni pico audio support working
2024-09-15 Raspberry Pi Pico 2 support working
2024-09-29 Add PWM audio support ...
    + Sounds quality, as may well be expected, is "poor". But does
    allow for a basic implementation using just a Pico and a few
    resistors and capacitors (i.e. no external DAC required)
2024-09-29 Clearer I2C LCD address configuration
2024-10-01 Updated schematic
    [picoX7.kicad_sch]
2024-10-01 Speculate support for back-pack I2C LCD
    For Waveshare DAC with I2C LCD use the alternate
    AlphaNumLcd class with I2C address 0x27
2024-10-04 Update Platform to speculate fix support for 16x2 LCD with I2C bridge
    XXX untested
2025-02-11 Updates for Lfo, and pitch EG
    - Not complete
2025-02-12 Temporary fix for broken pitch mod
2025-02-15 Pitch modulation fix
2025-02-20 Add conversion of MIDI velocity to internal representation
2025-02-20 Compensate for 48KHz native sample rates
2025-02-21 Switch to accurate scaled op levels
2025-02-24 Fix for fully off operators bleeding
    - This seems to limit the dynamic range of amp EGs?
    But is currently preferable to the bleeding.maybe
    the real thing does the same?
2025-04-16 Update hardware configs - Drop GPIO LCD support + Add general I2S config + Pin assignments moved to be more compatible with picoX21H project
    [picoX7.kicad_pcb, picoX7.kicad_sch, picoX7_WAVESHARE_REV2_1.kicad_sch]
2025-05-25 Fix for MIDI in and I2C LCD out on RP2350
    + Fixes are in Platform
2025-10-18 Switch to Hardware submodule
2025-12-28 Start to generalize the synth framework towards picoSynth
